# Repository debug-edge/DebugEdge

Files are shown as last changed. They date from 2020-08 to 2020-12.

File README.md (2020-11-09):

# Debug Edge
A small bridge board to link a programmer to a PCB, via a card edge connector.
See [debug-edge.io](https://debug-edge.io/) for more the full specification and rationale.

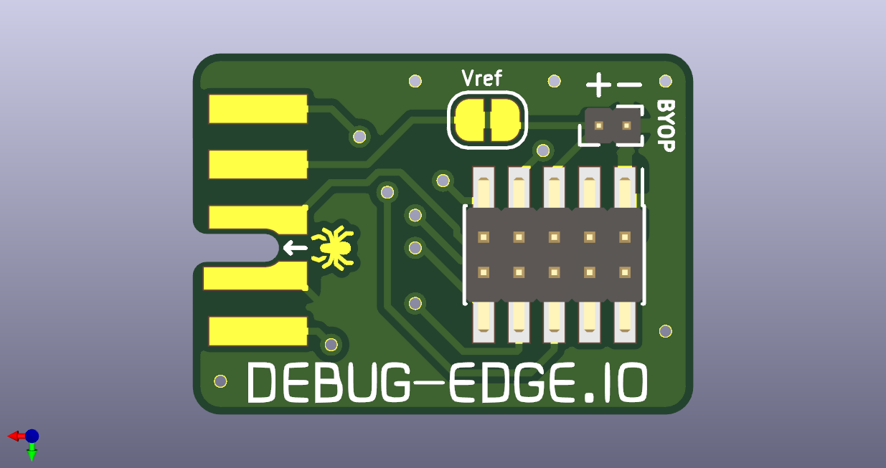
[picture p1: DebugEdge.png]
A 3d render of a completed DebugEdge PCB


The DebugEdge V1.1 specification

## Goals

A nice, easy to use debug/flash probe adapter that can quickly and easily connect to a board, staying put as you need it!

## Concept

Greg Davill [mentioned](https://twitter.com/GregDavill/status/1298419285086199808) coming across the AVX Open Ended Card Edge connector, and Scott Shawcroft [followed up](https://twitter.com/tannewt/status/1298422601811808256) that it'd be a good idea to explore a conversion from a typical 10-pin SWD/JTAG connector to the card edge format.

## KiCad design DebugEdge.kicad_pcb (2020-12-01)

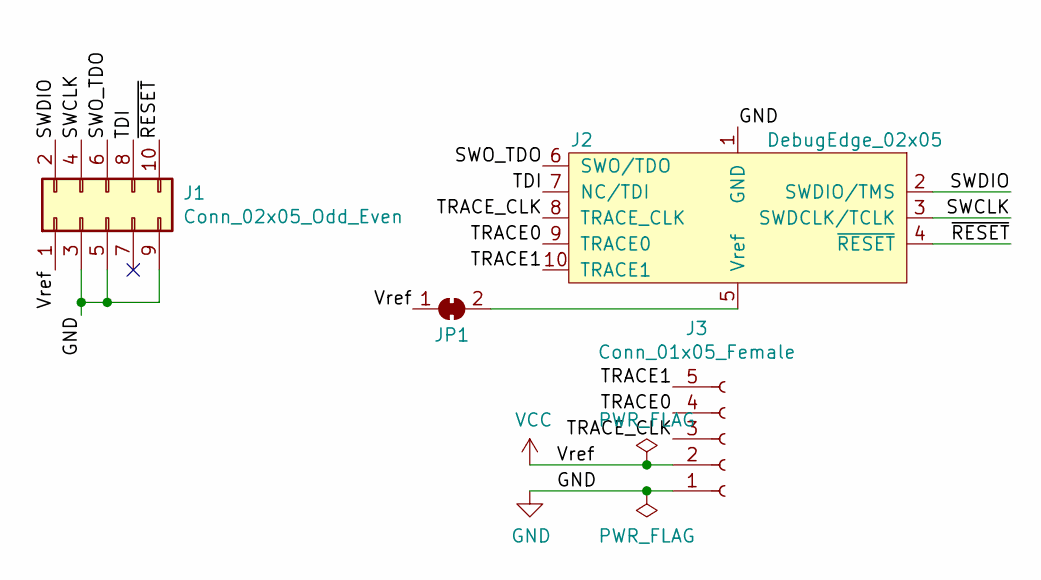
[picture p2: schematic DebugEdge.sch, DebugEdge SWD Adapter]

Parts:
J1: Conn_02x05_Odd_Even; PinHeader_2x05_P1.27mm_Vertical_SMD
J2: DebugEdge_02x05; DebugEdge_2x05_Host
J3: Conn_01x05_Female; PinSocket_1x05_P2.54mm_Vertical
JP1: SolderJumper_2_Bridged; SolderJumper-2_P1.3mm_Bridged_RoundedPad1.0x1.5mm

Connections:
/SWCLK: J1.4, J2.3 (SWDCLK/TCLK)
/SWDIO: J1.2, J2.2 (SWDIO/TMS)
/SWO_TDO: J1.6, J2.6 (SWO/TDO)
/TDI: J1.8, J2.7 (NC/TDI)
/TRACE0: J2.9 (TRACE0), J3.4
/TRACE1: J2.10 (TRACE1), J3.5
/TRACE_CLK: J2.8 (TRACE_CLK), J3.3
/~RESET~: J1.10, J2.4 (~RESET~)
GND: J1.3, J1.5, J1.9, J2.1 (GND), J3.1
unnamed: J2.5 (Vref), JP1.2 (B)
VCC: J1.1, J3.2, JP1.1 (A)

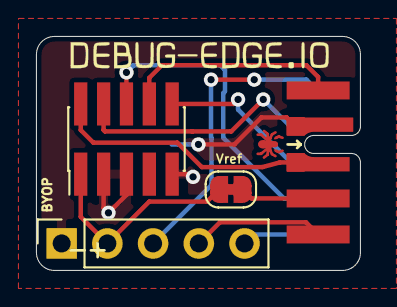
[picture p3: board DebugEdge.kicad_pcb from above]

Board: 2 copper layers, 18.0 x 13.0 mm, 5 parts (0 on the bottom side), 11 nets.

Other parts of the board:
Ref**: Val**; DebugEdge_URL_Silk

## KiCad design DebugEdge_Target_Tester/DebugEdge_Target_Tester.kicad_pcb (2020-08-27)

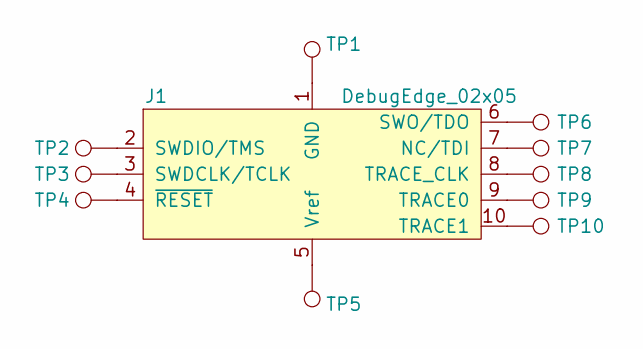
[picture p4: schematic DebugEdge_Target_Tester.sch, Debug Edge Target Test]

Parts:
J1: DebugEdge_02x05; DebugEdge_2x05_Target
TP1, TP2, TP3, TP4, TP5, TP6, TP7, TP8, TP9, TP10: TestPoint; Pin_D1.0mm_L10.0mm

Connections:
unnamed: J1.1 (GND), TP1.1
unnamed: J1.2 (SWDIO/TMS), TP2.1
unnamed: J1.3 (SWDCLK/TCLK), TP3.1
unnamed: J1.4 (~RESET~), TP4.1
unnamed: J1.5 (Vref), TP5.1
unnamed: J1.6 (SWO/TDO), TP6.1
unnamed: J1.7 (NC/TDI), TP7.1
unnamed: J1.8 (TRACE_CLK), TP8.1
unnamed: J1.9 (TRACE0), TP9.1
unnamed: J1.10 (TRACE1), TP10.1

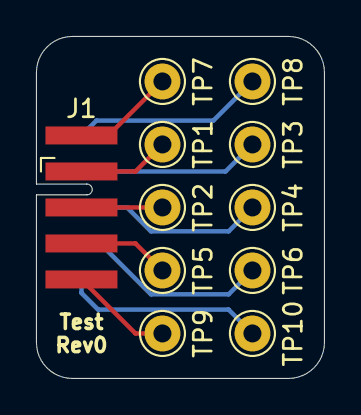
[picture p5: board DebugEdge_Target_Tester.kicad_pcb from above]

Board: 2 copper layers, 16.0 x 19.0 mm, 12 parts (1 on the bottom side), 10 nets.

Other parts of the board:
Ref**: Val**; DebugEdge_URL_Silk

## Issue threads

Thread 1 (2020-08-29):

Top silkscreen on host connector

k0d, 2020-08-29:
It feels like it's too much silkscreen, takes your eye away from the rest of the board.

Here is my suggestion.

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

nitz, 2020-08-29:
I'll let @tannewt chime in if he'd like, but in my opinion I feel like that's a bit of the point: to draw your eyes to it and be immediately recognizable.

I also think your render in particular makes it a bit more difficult to see there, since your pads are colored the same as the silk. When the pads are actually gold or silver, I think they stand out a bit more:
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

k0d, 2020-08-29:
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

This is what I think would look better. It looks great on the board I'm making...

k0d, 2020-08-29:
Maybe the targets silkscreen isn't great on my above render...

I also wonder...maybe we'd like to include some text or a little 'logo'? then it's even more recognisable....

nitz, 2020-08-29:
Yeah I did a very quick mspaint mockup where I just plopped a random little gear/arrow logo on one of Scott's images:
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

I'm definitely no artist, but I love the idea of a tiny logo that is an immediate "oh i know what this is" hint.

k0d, 2020-08-29:
Leave that to me...I'll produce some mock-ups in a couple of hours. :)

k0d, 2020-08-29:
Suggestion for the host connector.

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

nitz, 2020-08-29:
Ooh, that's fun! I definitely like the spider too. In my quick hunt for "debugging" related iconography I kept coming across things like this that I found on nounproject: 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)

Somehow the spider comes off a lot less "creepy" than the fewer-legged one. Plus I hear they're pretty good at eating bugs!

k0d, 2020-08-29:
haha...yeah, also...the target connector could have a web around it or something...not started to design that yet.

@tannewt your opinion?

k0d, 2020-08-29:
Host and target

Probably the arrows on the 'web' I'll change them...

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

k0d, 2020-08-29:
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

tannewt, 2020-08-29:
These look like neat ideas. The spider is a great idea! We could use that as the general logo too.

My main goal with the heavy silkscreen was to make the top easily distinguishable from the bottom.

I don't think we'll know what works best until we start seeing it on real boards. All of these renders are much larger that it will be in real life.

nitz, 2020-08-29:
That's a really good point. I swear I need to get a to-scale model of a quarter and keep it every board I do. Sounds like the first spins at oshpark are already at the fab so hopefully we'll get it a good look quickly!

k0d, 2020-08-29:
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

This is a minimalist version of it.

I'm going to order a prototype board for a project tomorrow, I'll order a board with each of my examples to compare.

Yes, I was thinking we can use the spider as a logo also.

tannewt, 2020-08-29:
@k0d do you not like the slanted pads? I like having a version that would work without silkscreen.

k0d, 2020-08-29:
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

Personally...no I don't like them...but I agree with you...

k0d, 2020-08-29:
It's hard to get the spider+text to be nice with the slants...but I'm working on it...

tannewt, 2020-08-29:
I'm ok omitting the text too and just having the spider.

nitz, 2020-08-29:
I agree with that. The spider is something that would be recognizable, and something someone could google "spider connector" or something like that 😂

k0d, 2020-08-29:
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

What do you think of the bottom left one? I will fix the slanted pads...

k0d, 2020-08-29:
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

Green + HASL. (This is what my next board will be...so I am keen to make it look nice on it)

k0d, 2020-08-29:
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

k0d, 2020-08-29:
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

I feel this is the 'final design' from my point of view...so now it's up to you to let me know what you think, should I change anything and if you want to use it.

nitz, 2020-08-29:
I actually _really_ like it. The IC shape on the target side side is super cute. I don't know how it would work at that scale, but you gave me the idea of trying to put like, a "webbing" inside of it. Excusing my (very) poor mspaint rendition:

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
(Or like you have with the chip, then use mask to 'paint' the web lines?)

Again, I know it's super tiny and I'm not sure how well it'd look at that scale, but I feel like it would hit the theme spot on.

You also gave me an idea for a swankied up wordmark with the way you did the in/out style like that:

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

k0d, 2020-08-29:
I think its a no with the web....too small, am already pushing the limits as it is.

The Logo...nice start. Will think about that tomorrow...

tannewt, 2020-08-30:
I really like the spider on one side and the ic on the other!

On Sat, Aug 29, 2020, at 4:00 PM, Mark Olsson wrote:
>

> I think its a no with the web....too small, am already pushing the limits as it is.

> The Logo...nice start. Will think about that tomorrow...

> —
> You are receiving this because you were mentioned.
> Reply to this email directly, view it on GitHub <https://github.com/debug-edge/DebugEdge/issues/1#issuecomment-683350750>, or unsubscribe <https://github.com/notifications/unsubscribe-auth/AAAM3KP2B6TCSGJELRUIU7TSDGB7TANCNFSM4QPCDQKA>.

k0d, 2020-08-30:
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

I've changed the silkscreen a little...and optimised the images...as it took like 1 minute to do the copper flood fill command as there was so many edges for it to work around...now it's normal speed.

If you like this...I'm going to order a prototype of a board I'm going to be selling...which I want to use this connector on. I understand it's still work in progress, but I'd like to get as close to a real connector as possible so any prototype users will not get confused if it's changed a lot.

tannewt, 2020-08-30:
I was thinking the slant would peak at the slot. For the target side I wanted a slant as well as to make the gnd pin stick out further to “fit” into the host “plug”.

On Sun, Aug 30, 2020, at 11:10 AM, Mark Olsson wrote:
>

> Screenshot 2020-08-30 at 20 08 08 <https://user-images.githubusercontent.com/547698/91666384-8909cb00-eafc-11ea-87ab-6494b866a4c7.png>

> I've changed the silkscreen a little...and optimised the images...as it took like 1 minute to do the copper flood fill command as there was so many edges for it to work around...now it's normal speed.

> If you like this...I'm going to order a prototype of a board I'm going to be selling...which I want to use this connector on. I understand it's still work in progress, but I'd like to get as close to a real connector as possible so any prototype users will not get confused if it's changed a lot.

> —
> You are receiving this because you were mentioned.
> Reply to this email directly, view it on GitHub <https://github.com/debug-edge/DebugEdge/issues/1#issuecomment-683451995>, or unsubscribe <https://github.com/notifications/unsubscribe-auth/AAAM3KKTUVRY7KFDJCOBRH3SDKIZPANCNFSM4QPCDQKA>.

k0d, 2020-08-30:
Ok...I need a bit more info about that, I don't really understand what you want to achieve with it...

tannewt, 2020-08-30:
Sorry. I’m on my phone so I’m a bit limited. For the target, I was going to set back all pins except gnd by the same amount as the gnd pin on the host. That help? Otherwise I can try and implement it later.

On Sun, Aug 30, 2020, at 11:36 AM, Mark Olsson wrote:
>

> Ok...I need a bit more info about that, I don't really understand what you want to achieve with it...

> —
> You are receiving this because you were mentioned.
> Reply to this email directly, view it on GitHub <https://github.com/debug-edge/DebugEdge/issues/1#issuecomment-683454704>, or unsubscribe <https://github.com/notifications/unsubscribe-auth/AAAM3KLGFB5NWHGJLEU5B6LSDKLZVANCNFSM4QPCDQKA>.

k0d, 2020-08-30:
Ok, I get that...was there a technical reason, or purely cosmetic?

tannewt, 2020-08-30:
Mostly cosmetic. It will also connect the gnd pin before the others when the target is connected second which is better I think.

On Sun, Aug 30, 2020, at 11:41 AM, Mark Olsson wrote:
>
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
k0d, 2020-08-30:
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

It didn't look nice having the arrow point 'in' on the target...what about this?

k0d, 2020-08-30:
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

Clearance of the connector...you still can see the 'icons'...

k0d, 2020-08-30:
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

"Final version" ;)

tannewt, 2020-08-30:
Looks great!

On Sun, Aug 30, 2020, at 2:40 PM, Mark Olsson wrote:
>

> Screenshot 2020-08-30 at 23 36 28 <https://user-images.githubusercontent.com/547698/91669983-a26d4000-eb19-11ea-8448-2e393e0a9df0.png>

> Screenshot 2020-08-30 at 23 38 48 <https://user-images.githubusercontent.com/547698/91670024-f6782480-eb19-11ea-9b28-612154a00428.png>

> Screenshot 2020-08-30 at 23 40 01 <https://user-images.githubusercontent.com/547698/91670052-232c3c00-eb1a-11ea-989c-e9cba799d5b1.png>

> "Final version" ;)

> —
> You are receiving this because you were mentioned.
> Reply to this email directly, view it on GitHub <https://github.com/debug-edge/DebugEdge/issues/1#issuecomment-683474085>, or unsubscribe <https://github.com/notifications/unsubscribe-auth/AAAM3KJDAGHV23UJL3UZSETSDLBN7ANCNFSM4QPCDQKA>.

nitz, 2020-08-31:
Absolutely fantastic. I really appreciate all the work you're putting into this. The footprint looks so dang awesome!

tannewt, 2020-08-31:
@k0d You should have permissions to push all of this to the repo.

k0d, 2020-08-31:
Yeah....will tidy things up, and push in the next couple of days.

k0d, 2020-09-12:
I have boards now, they work well. However the silkscreen and spidey/mcu logos are a bit hard to see. I want to make some small changes, but nothing major.

k0d, 2020-09-12:
Quite a big change...but it'll be much easier to recognise the footprint.

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

k0d, 2020-09-12:
OLD:
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
NEW:
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

k0d, 2020-09-12:
I like this....and you @nitz @tannewt ?

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

tannewt, 2020-09-12:
I like that the arrow is clearer but why straighten the pads?

On Sat, Sep 12, 2020, at 12:37 AM, Mark Olsson wrote:
>

> I like this....and you @nitz <https://github.com/nitz> @tannewt <https://github.com/tannewt> ?

> Screenshot 2020-09-12 at 09 36 41 <https://user-images.githubusercontent.com/547698/92990296-85eae380-f4db-11ea-89fc-8bbe0f421b12.png>

> Screenshot 2020-09-12 at 09 35 08 <https://user-images.githubusercontent.com/547698/92990293-82575c80-f4db-11ea-8de3-7e72787f4c6e.png>

> —
> You are receiving this because you were mentioned.
> Reply to this email directly, view it on GitHub <https://github.com/debug-edge/DebugEdge/issues/1#issuecomment-691435830>, or unsubscribe <https://github.com/notifications/unsubscribe-auth/AAAM3KKHLYC74YEBBIL4LATSFMQMLANCNFSM4QPCDQKA>.

k0d, 2020-09-12:
I had to make the MCU bigger...so the pads had to be straight...but on the back...they're still pointed.

I think this makes it clearer which side is which.

tannewt, 2020-09-12:
Ok! Thanks for iterating on the design.

On Sat, Sep 12, 2020, at 12:45 AM, Mark Olsson wrote:
>

> I had to make the MCU bigger...so the pads had to be straight...but on the back...they're still pointed.

> I think this makes it clearer which side is which.

> —
> You are receiving this because you were mentioned.
> Reply to this email directly, view it on GitHub <https://github.com/debug-edge/DebugEdge/issues/1#issuecomment-691437109>, or unsubscribe <https://github.com/notifications/unsubscribe-auth/AAAM3KNBNH225AKDKJYDX73SFMRI7ANCNFSM4QPCDQKA>.

k0d, 2020-09-12:
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

Ok, so I think I'm done with my updates. I like the MCU a lot more. It will be way easier to get fab'd, I've also updated Spidey a little so he's more fab'able.

nitz, 2020-09-12:
Is the center of the IC art just bare FR4? Cause that's super clever!

I kinda liked the way the spider was "holding" the arrow" before, but I will definitely yield that it is certainly clearer.

I'm thrilled with your artistic ability :)

k0d, 2020-09-12:
Yeah, it's bare FR4. It really helps with the 0.2mm solder mask spacing requirement. I really like how it looks, especially on the green/HASL which is what I have to use a lot of the time. Next order I do will have black/ENIG though.

I also liked it that the spider was spinning an arrow-web, but I think we have to go with clarity in this case. We could of course make the logo have it spinning the arrow...I've not thought much about that yet.

Closed 2020-09-28.

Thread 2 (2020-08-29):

Pin 1 silkscreen

k0d, 2020-08-29:
The purpose of the marking for pin 1 in the case of this connector is to show if it's up or down. But the connector has a logo on the top, and an arrow pointing at their pin 1. So I suggest we change the silkscreen to show what is up...not which is pin 1.

**'The issue'**
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

**'The fix'**
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

nitz, 2020-08-29:
The pin 1 marking is definitely partially a "this side up" indicator (and is definitely not any more than that on the first oshpark spins.) The shortening/lengthening of pin 1 on the host/device sides respectively was thought to keep that "this side up", as well as ideally be a "ground is connected before everything else" feature, assuming you're attaching to the target second.

As it is now, the bottom side of the FP has no silk whatsoever, so any silk would signify the top, in addition to the shortened/lengthened pin1.

I wish we could stay 'in sync' with the AVX pin one, but their pin 1 varies based on the number of positions in the connector, and we want to "grow" from the 4p to the 10p, only adding pin positions rather than moving/adding.

k0d, 2020-08-29:
Yeah...I totally agree that it'd have been nicer to match their pin 1, but as we can't...I guess it's good to just forget indicating pin 1.

In general, I'm a "minimalist silkscreen guy", so you'll see why I wanted to make it a bit less...

k0d, 2020-08-29:
Closing because #1 can cover both issues.

Closed 2020-08-29.

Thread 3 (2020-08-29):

Orientation of connector

k0d, 2020-08-29:
As you can see in the photo below, the logo on the connector is closest to the target side, not the host side. Is that what we want? It's ok if it is :) Just making sure.

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

nitz, 2020-08-29:
It honestly wasn't really a consideration when I started laying out the footprint. I figured it had to go on one of the sides, and I typically have my debugger/flasher sitting "above" my board on my desk, and had just imagined it all from that angle, if you will.

I'm not sure if there's really a right answer though. My biggest concern is just making sure it's connected correctly, I think.

k0d, 2020-08-29:
I agree with you....just wanted to check that it was considered and you're ok with it. Not sure if you tested with a 3d model...

nitz, 2020-08-29:
Haha, nope, I hadn't. I have a little 3D printed origin axis model I keep on my desk and used it to try and visualize the rotations, but that was about as far as I got 🙂

Though I'm gonna keep this open now because it makes sense to add one to the kicad preview.

k0d, 2020-08-29:
The thing with the preview is you want to see it with and without the connector...that's why I did it half on...but I'm not sure...I know you can turn off the render of the 3d models...not sure what's best...I don't have much of an opinion on that.

siddacious, 2020-08-31:
This caught my attention because it reminds me of how trivial but also satisfying it is to have finally figured out the "best" way to plug in USB type A connectors, with the thick/male side "down". I'm also noticing just now that the logo on type A cables is seemingly always "up" or on the side opposite the contacts/male part.

With that in mind, to the extent that there is an "up" or side that should be a focus, _ideally_ the logo would be on the same side. Other considerations should likely take precedence, but it's worth considering, I think.

k0d, 2020-09-12:
You don't need to look at the logo/arrow on the connector as you can put it either way round...you orientate it according to the footprint design.

siddacious, 2020-09-15:
oh derp, ya there's only one sensible way to plug 'er in. I have eyes, I swear!

Closed 2020-09-12.

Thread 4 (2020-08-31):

VRef on the connector

k0d, 2020-08-31:
VRef is used on the JTAG connector to detect the target's voltage. It shouldn't be used to supply power to the target.

So, if we want to provide power with debug-edge, then we need to change it to VCC. Or if we use it as VRef, then the connector is still BYOP.

I prefer to have VRef, so it's then more compatible with the ARM/JTAG 10 pin connectors.

Maybe confusing and not 100% checked yet...but here is the pinouts of various connectors.

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

nitz, 2020-08-31:
Yeah, Vref may be a bit of a misnomer, but I'll explain how we got there and see what you think:

I started from the JTAG/SWD interface [directly from Keil's ULINKplus](https://www.keil.com/support/man/docs/ulinkplus/ulinkplus_jtagswd_interface.htm) In that, they call it VCC. The CMSIS-DAP (DAPLink) adapter I was currently using (as in, sitting on my desk at the moment) also uses VCC as one of it's 5 pins (VCC,GND,SWDIO,SWCLK,nRESET).

I think it was when @tannewt I were looking at seeing that it could support lots of different protocols that we swapped it to Vref, because it didn't _necessarily_ need to supply power in some of those cases. I really can't tell if it's something we should be naming "VCC/Vref", naming something else, or how to deal with it exactly.

If you want a real confusing rabbit hole to dig down, check out all the different names/'functions' [ST](https://www.st.com/resource/en/user_manual/dm00026748-st-link-v2-in-circuit-debugger-programmer-for-stm8-and-stm32-stmicroelectronics.pdf) uses for essentially the same pin: VDD, Target VCC, MCU VCC, MCU VDD, VAPP.

Maybe we need a whole new name that is all of those, *plus* the potential of Vref?

k0d, 2020-08-31:
On the STLink v3 board, it's connected to a voltage divider that the STLink MCU uses to detect the target voltage.

If we called it VCC, then I'd expect it to supply voltage...which a STDC14 to Debug-Edge adapter board would not. On JTAG there is a pin (19 I think) which is 5v supply, that's VCC in my view.

What's the CMSIS-DAP connector you have?

This one https://github.com/ARMmbed/mbed-HDK-Eagle-Projects/blob/master/DAPLink/Probes/SWDAP/v1.0.0/SWDAP-v1.0.0-SCH.pdf is kind of an official one, and VCC isn't connected. It's meant to be T_VCC...but they don't label it as that it seems.

OpenOCD uses the target voltage detection sometimes to do then flash programming. It can fail sometimes if you don't use it.

My suggestion is we keep VRef and use it as T_VCC (don't connect to H_VCC), but maybe it's good to get other people into this discussion. Maybe @ladyada @arturo182 ?

k0d, 2020-08-31:
Hmm, off course, if you supply 3v3 on the VRef to the target, then the target's VCC will be 3v3, which is what it'd detect. So I guess it depends on if the H_VCC line can supply enough mAh to the target.

I think it's ok to use it as both....but...we should clearly mark that VRef might not supply current in the debug-edge docs. That's the biggest issue with other connector specs, it's not clearly communicated.

k0d, 2020-08-31:
Oh....should we add a marking on the VRef pin to indicate if it supplies power? then the board developer can choose to show it or not.

nitz, 2020-08-31:
^ That was along the lines of what I was thinking, but I couldn't come up with a clean (read: tiny) way to say "this *might* supply power, depending on your adapter/protocol/etc." Any ideas?

k0d, 2020-08-31:
My board I'm making right now will not supply power, so it doesn't matter for me today.

nitz, 2020-08-31:
That's good at least! Yeah that's why I had the little solder bridge there
that can be cut on the Vref line on the host board side, because I'm not
quite sure what the right answer is yet, too!

On Mon, Aug 31, 2020 at 9:39 AM Mark Olsson <notifications@github.com>
wrote:

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

tannewt, 2020-08-31:
I wasn't thinking it'd supply power. There should definitely be a way to power it separately.

Closed 2020-09-28.

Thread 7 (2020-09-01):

Slot issues

k0d, 2020-09-01:
JLCPCB can't produce the 0.6mm slot as their minimum is 1.0mm.

So I don't know if we should widen the slot, or if I should move to another connector on my boards. It's quite important I can use JLCPCB....

k0d, 2020-09-01:
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

I think I'm going to try this...

k0d, 2020-09-01:
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

Target

nitz, 2020-09-01:
Hm. Let me see if I can find something with a 1mm slot around the office here, and I'll see how much play the adapter has when I get home.

I will say, the grip it has on the board itself (with just the plastic, not to mention the pins), makes me think that it's *probably* not  an issue for a wider slot.

A fun fact, OshPark told me they actually had to modify some of their tooling for the slot too. Seems like the 0.6mm is a bit of a wrench in PCB manufacture's plans! No chance we can get JLCPCB to be as accommodating as Oshpark? ;D

k0d, 2020-09-01:
I ordered the boards...so I'll be able to test properly in a week or so....Hopefully it'll be fine.

tannewt, 2020-09-06:
I think the 1mm slot is fine. @k0d can you push your latest footprints? I want to add it to some boards too.

k0d, 2020-09-06:
Sure, I'll do it today. I was waiting until my boards came, that's why I didn't do it yet ;)

nitz, 2020-09-07:
Looks like my oshpark boards should be in tomorrow, so I'll get a chance to see how the 0.6mm slot works. If I'm feeling squirrely, on Wednesday at the office I might take the dremel to one and widen it out to see how it feels too! (assuming I don't completely botch the pads 😂

k0d, 2020-09-12:
1.0mm slot works just fine.

nitz, 2020-09-12:
Hell yeah! Great stuff, Mark!

Closed 2020-09-12.

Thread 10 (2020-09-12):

3d model for KiCAD preview

k0d, 2020-09-12:
Discussed in issue #3

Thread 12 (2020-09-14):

jtag/uart pinout suggestion

gsteiert, 2020-09-14:
I like where this is going, but it would be really nice to fit the uart in the 8 pin option.
I would suggest this as an enhanced pinout for jtag/uart options:
1 GND
2 SWDIO/TMS
3 SWCLK/TCK
4 nRESET
5 Vref
6 SWO/TRACE_CLK
7 TDI/RX
8 TDO/TX
9 TRACE0
A TRACE1

This would allow uart in the 8 pin option and all the pin directions will match.
Also, most chips only have swo or trace, so sharing the swo pin with trace makes more sense (I know that is not how arm did it)

nitz, 2020-09-15:
This makes pretty decent sense to me. I'm not super familiar with JTAG myself, but it seems plausible that if you're using TDI/TDO you're either already using the trace pins or have other means of getting the UART.

I also appreciate the symmetry of lining up the RX/TDI (both would be data to target from host), and TX/TDO (to host from target).

tannewt, 2020-09-27:
I purposefully avoided sharing JTAG with UART so that one could use them concurrently. My compromise was to have TX on the 8 pin so that debug output could be done at least.

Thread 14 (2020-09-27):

Create a logo for debug-edge

k0d, 2020-09-27:

k0d, 2020-09-27:
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

I made one...like it?

k0d, 2020-09-27:
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

...or we could go blue?

k0d, 2020-09-27:
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

...or even green?

nitz, 2020-09-27:
Ahhh, I like it. I'm always a fan of purple not only because of oshpark, but also cause pink and purple are my favorite colors, but they honestly all look fantastic.

Also blue should be a more common pcb color, it's so fun.

cotdp, 2020-09-27:
+1 for purple :)

k0d, 2020-09-28:
Thing is, with purple, everyone thinks of OSHPark, which concerns me only because we're not associated with them. I kinda like the blue one. By the way...these are not made in KiCAD, but 'sketch', so they're proper artwork.

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

Here's a white version for if we want a dark background. I won't make yellow, red or black.

k0d, 2020-09-28:
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

@nitz Here's one just for you

nitz, 2020-09-28:
You spoil me 🥰🥰

k0d, 2020-09-30:
@tannewt your views?

tannewt, 2020-10-05:
Sorry I missed this. Where do you want to use the logo? Seems to me that is should be simpler. Maybe just the spider pointing to the chip?

k0d, 2020-10-05:
I was thinking top of the webpage for example...but I do think having a simpler icon is also good.
So what I've designed so far is a 'titlebar', and I'll make an 'icon'. Sound good?

tannewt, 2020-10-06:
Sure, I'd start with the logo and then create the rest of the design.

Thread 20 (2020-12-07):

Snap-off footprint

nitz, 2020-12-07:
This idea wasn't directly brought up via the recent Twitter/HaD discussion (maybe it was and I missed it,) but I got to thinking of the potential feasibility of a snapaway(™? haha) footprint.

To elaborate: The snapaway flavor of the D-E footprint would live on a small dongle protruding from the side of the target. The protrusion is only connected via a very small bridge of FR4, just wide enough for the traces to head back to the PCB proper. When the target is no longer needed to be "debugged" (say, being put in an enclosure, test units being transformed for production, etc,) the D-E header can be snapped off, thanks to the drills on the small bridge (like fabs would typically use for depanelization.)

A crude non-artist's rendition:
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

Obviously this would add to overall board space, which could be a concern to cost per board (esp in those that bill by overall rectangle size,) but would offer a reasonable use case for projects that look to be able to go directly from a "debugable" to production design.

PTHs could also be placed on the traces headed out to the D-E, allowing those who seek a "pogo pin jiggable" design for production, allowing them the best of both worlds.

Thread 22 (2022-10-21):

Suggestion for enhancement

DanRoh, 2022-10-21:
I like the idea to use the (cheap, small, ..) AVX edge connector as a debug interface. I also found the information on **debug-edge.io** very clearly structured and inspiring.. Thanks for this.

Recently I added the edge connector to one of my target boards and found it a bit confusing how exactly the pin assignment is meant. I guess the drawing on debug-edge.io is a "view towards the target board"?

I know I could find out by opening the KiCad files, but for us out there without KiCad it's a bit difficult..
May I suggest to place a small note on the drawing?

I also have a suggestion to extend the meaning/description of some pin assignments:

**Vref**: I think this normally is meant to be output from the target board and used as a reference voltage for the interface drivers on the interface side.
However, I often use this to power the target board during production programming and I think many developers do it this way.. What about naming this "**Vref/Vcc**"? This also would suggest that it is "bidirectional".

**TRACE0/1**: If I'm correct the signals TRACE_CLK, TRACE0, TRACE1 are normally output from the target to the host. You already specified that TRACE0 can also be used as RX, which is input to the target, i.e. TRACE0/RX is bidirectional.
I would like to suggest to change the specification for the TRACE signals like this:
**TRACE_CLK/TX**   (no change)
**TRACE0/RX/IO0**  (added IO0, suggest use of general purpose bidirectional I/O)
**TRACE1/IO1**     (added IO1, suggest use of general purpose bidirectional I/O)

This would then look like this:
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

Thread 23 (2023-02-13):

DebugEdge incompatible to STLINK-V3MINIE BTB pinout

marcusgrtz, 2023-02-13:
STMicroelectronics uses the same edge connector on their [STLINK-V3MINIE](https://www.st.com/en/development-tools/stlink-v3minie.html) in-circuit debugger with a different pinout.
The pinout of the 10pin “BTB card edge connector” is described in the manual [UM2910](https://www.st.com/resource/en/user_manual/um2910-stlinkv3minie-debuggerprogrammer-tiny-probe-for-stm32-microcontrollers-stmicroelectronics.pdf) in section 6.2.

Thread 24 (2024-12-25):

DebugEdge_2x03_Target.kicad_mod fails design rules checker in Kicad 8.0

jcard0na, 2024-12-25:
I just found this very cool project.  Thanks for making it available to the world!

When I tried to use it in a new design, I get a bunch of Design Rules Checker error in Kicad that are triggered by the cute logo:

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

The fix is simple:  just remove or move to silkscreen like below.

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

If anyone is maintaining this, I'm happy to provide a pull request.

Cheers,

tannewt, 2024-12-26:
I'm around to merge. Haven't been using it myself though.

jcard0na, 2024-12-26:
Thanks @tannewt
If I end up building a board with this, I'll send a PR.  For the moment, at least this issue documents the problem and provides one possible solution.

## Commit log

2020-08-26 First revision of OpenClip.
    [OpenClip.kicad_pcb, OpenClip.sch]
2020-08-26 Renaming OpenClip to DebugEdge, adopt v1 of 10 pinout.
    [DebugEdge.kicad_pcb, DebugEdge.sch, OpenClip.kicad_pcb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]
2020-08-27 Add solder bridge for Vref & BYOP pins.
    BYOP in case you need to bring your own power!
    [DebugEdge.kicad_pcb, DebugEdge.sch]
2020-08-27 Fix pin 1 silk, add 2x5 target FP.
    [DebugEdge.kicad_pcb]
2020-08-27 Fix mask on bottom. Remove paste.
    [DebugEdge.kicad_pcb, DebugEdge.sch]
2020-08-27 Add target test board.
    [DebugEdge_Target_Tester.kicad_pcb, DebugEdge_Target_Tester.sch]
2020-08-27 Expanded edge to let ground pour flow.
    And rounded the corners, cause why not?
    [DebugEdge.kicad_pcb]
2020-08-27 Expanded board.
    Gives more room for a box header if one is used.
    [DebugEdge.kicad_pcb]
2020-08-28 Taper pads and add silk to top side
    [DebugEdge.kicad_pcb]
2020-08-28 Port the tapers to footprint.
2020-09-06 Updated both Host and Target footprints with the new design Spider/MCU icon Extended GND pin 1.0mm slot (as its hard to fab 0.6mm it seems)
2020-09-13 Added 2x2, 2x3, 2x4 target edge footprints.
2020-09-13 Marked the 2x5 footprints virtual.
2020-09-27 Update host adapter to new footprint
    [DebugEdge.kicad_pcb, DebugEdge.sch]
2020-11-27 change 2x5 adapter to swd/jtag pinout
    [DebugEdge.kicad_pcb, DebugEdge.sch]
